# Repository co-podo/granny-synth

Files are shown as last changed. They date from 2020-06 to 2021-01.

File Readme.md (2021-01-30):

# Granny Synth

Adrian Ludwig
 Im Sack 11
 86152 Augsburg
 +49 157 71704314
hello@adrianludwig.de

Codrin Podoleanu
 Liebigstraße 61
 64293 Darmstadt
 +49 152 52022433
codrin.podoleanu@hs-augsburg.de

#### Abstract

GrannySynth ist ein Prototyp für ein Hard-/Softwaresystem für Granularsynthese in Echtzeit für Liveperformances und Sounddesign. Er enstand 2020 im Kurs "Interaktion/Programmierung" bei Prof. Dr. Thomas Rist an der Hochschule Augsburg. Eine Videodemonstration des Systems finden Sie [hier](https://vimeo.com/506451315).

 #### Klassifizierung und Einordnung

C.3 [SPECIAL-PURPOSE AND APPLICATION-BASED SYSTEMS] *,* H5.5 [SOUND AND MUSIC COMPUTING], [H.5.2](http://www.acm.org/about/class/ccs98-html#H.5.2) [USER INTERFACES]

#### General Terms

Design, Experimentation, Soundsynthesis

#### Keywords

Granularsynthese, Raspberry Pi, Pure Data, Liveperformance

#### 1. Motivation

##### Problemstellung: Granulare Synthese 

Wir interessieren uns für das Feld des Sounddesigns und suchen nach neuen Mitteln für Klanggestaltung. Eine sehr vielseitige Möglichkeit Klänge zu Formen ist die sogenannte "Granularsynthese". Vor allem in der Improvisation lassen sich mit dieser Syntheseart stark eigenständige, eindrucksvolle Klänge erzeugen.

Da es sich um eine digitale Syntheseart handelt, gibt es bereits ein Vielzahl an Software-Synthesizern. Diese eignen sich für die Liveperformance nur bedingt, benötigen sie doch immer einen Rechner mit einer entsprechenden DAW. Vor allem in der Außenwahrnehmung durch Publikum entsteht dabei häufig der Eindruck, dass weniger Live auf der Bühne geschieht, als dass vieles vom Rechner abgespielt wird. Diese Wahrnehmung ist verständlich, sieht es manchmal doch tatsächlich so aus, als würde man seine Mails checken, wenn man angestrengt auf einen Bildschirm sieht. 

Ziel von Granny Synth ist es, dieses Problem zu beseitigen, indem auf Basis eines Kleinstrechners und geeigneter Interfacegestaltung ein Liveperformance-geeigneter Granularsynthesesystem gestaltet wird.

Dieses Paper beschreibt die Erstellung eines Prototypen des Systems "Granny Synth". Folgende Schritte werden im folgenden durchlaufen:

- Motivation

- Verwandte Arbeiten

- Anwendungszenarion

  - Anwendungsfall allgemein
  - Konkreter Anwendungsfall

- Entwurf des Prototyps

  - Technischer Ansatz
  - Konzeptueller Aufbau des Prototypen

- Implementierung

  - Hard- und Softwareumgebung
  - Kern der Implementierung
  - Umfang des Prototypen

- Evaluation

  - Ziele der Evaluation und Methodik
  - Durchführung der Evaluation
  - Interpretation der Evaluationsergebnisse

- Zusammenfassung

  - Erzielte Ergebnisse
  - Erweiterungsmöglchkeiten

#### 2. Verwandte Arbeiten

Wie in der Motivation beschrieben, gibt es bereits eine Vielzahl von Softwarelösungen für Granulare Synthese. Ein Prominentes Beispiel ist der in Ableton Live (Digital Audio Workstation) verfügbare [Granulator]( https://www.monolake.de/technology/granulator.html)

Diese Implementierung der Granularsynthese besticht durch eine vielzahl von Parametern und eine Verhältnismäßig einfache Bedienbarkeit. Dazu trägt insbesondere das sinnvoll gestaltete Bedieninterface entscheidend bei. 

In der Welt der Hardware finden sich vergleichsweise wenig Implementierungen von brauchbarer Granularsynthese. Am häufigsten noch sind Lösungen im Bereich der Modularen Synthesizersysteme zu finden. Ein prominentes Beispiel hier ist [Mutable Instruments Clouds Eurorack-Modul](https://mutable-instruments.net/modules/clouds/ ). Hier besteht das Problem, dass man darauf angewiesen ist, ein entsprechendes Rack mit allen weiteren nötigen Modulen aufzubauen. Das ist aufwändig und vor allem teuer.

Ein System, das aufgrund seines Aufbaus viele Arten der Synthese zulässt, indem es auf die Open Source Software "Pure Data" zurückgreift, ist [Critter and Guitaris Organelle](https://www.critterandguitari.com/organelle). Dabei kommt es auf die Community an, die neue Patches auch frei zur Verfügung stellen kann. Dieses System funktioniert sehr gut, ist aber Aufgrund kleiner Auflagen eher teuer.

Aufgrund dieser vorhergehenden Arbeiten soll mit "Granny Synth" eine Lösung für entscheidende Probleme der genannten Beispiele geschaffen werden. 

Der Klangerzeugungsaufbau und die Modulationsparamter des Granulator dienen als Grundlage zur Gestaltung der Softwareseite.

Als Basis für das System soll - wie bei Critter and Guitaris "Organelle" ein Raspberry Pi und Pure Data dienen. Im Gegensatz zur Organelle setzen wir explizit auf granulare Synthese, sowie auf niedrigere Kosten.

#### 3.Anwendungsszenario & Use Case

##### 3.1 Portabler Granularsynthesizer

Entwicklung eines portablen, preiswerten Granularsynthesizers. Nutzer:innen sollen mit dem Gerät ein flexibles, portables Gerät für die Liveanwendung von Granularsynthese zur Hand haben. 

##### 3.2 Definition der Use Cases

Die wichtigsten Uses Cases werden im Folgenden erläutert.

###### 	3.2.1 Hardwaresystem für Granularsynthese

Ein:e Nutzer:in benutzt das System um einen Granularen Synthesizer zu steuern. Dafür werden die eingesetzten Hardwarekomponenten zur Kommunikation zwischen Akteur:in und Hardwaresystem genutzt. 
  - User dreht Encoder im Uhrzeigersinn: 
       Inkrement eines Parameterwertes

  - User dreht Encoder gegen Uhrzeigersinn: 
       Dekrement einesParameterwertes

  - User drückt Encoder nach unten: 
       Modus des jeweiligen Encoders wird ausgewählt

###### 3.2.2 Modulares Hardwaresystem zur Bedienung von Pure Data 

Ein:e Nutzer:in definiert ein eigenes Pure Data Patch, das über die vorhandene Hardware gesteuert werden kann. Hierfür muss die Nutzer:in eine entsprechende Konfigurationsdatei für die Hardware, sowie ein „Pure Data“- Patch anlegen.

#### 4. **Entwurf des Prototyps**

##### 4.1 Technischer Ansatz

Das Gerät basiert auf der Hardwareseite aus einem Raspberry-pi 3, Fünf Ky-040 Drehencodern, sowie einem 20x4 Zeichen LCD Display. Die Komponenten befinden sich in einem einfachen, aus Holz gefertigten Gehäuse.
Zur Verarbeitung der IO-Befehle verwenden wir python und die zum Raspberry korrespondierende python Library RPi.GPIO. 
Als System für die Granularsynthese verwendet das System die Open Source Software „Pure Data“. 
Die Kommunikation zwischen GPIO und Pure Data erfolgt über das OSC-Protokoll.

##### 4.2 **Konzeptueller Aufbau des Prototypen**

Das System besteht aus mehreren, miteinander kommunizierenden Untersystemen. 

###### 4.2.1 GPIO - Server

Die Verarbeitung der Sensordaten erfolgt über einen GPIO-Server, der die entsprechenden Inputs und Outputs überwacht. Er empfängt die Signale von Encodern und Display und handlet die Ausgabe von Daten an das Display.

###### 4.2.2 OSC-Client

Die Kommunikation der GPIO Signale zur Audioverarbeitungssoftware erfolgt über einen OSC-Client.

###### 4.2.3 OSC-Server

In der Umgebung des Klangerzeugers empfängt ein Server die über OSC Übertragenen Befehle zur Kontrolle des Klangerzeugers.

###### 4.2.4. Klangerzeuger/Granularer Synthesizer

Die Audioverarbeitung erfolgt über eine eigene Sofware, in diesem Fall „Pure Data“.
Innerhalb der Software wird ein „Patch“ für die Granularsynthese angefertigt. Die Steuerung erfolgt über OSC. Das Programm steuert auch die Audioausgabe auf dem Gerät.

#### 5. Implementierung

##### 5.1. Hard- und Softwareumgebung

###### Hardware

- 5 x KY-040 Drehimpulsgeber
- 1 x 20x4 LCD-Display
- 1 x IC2 Adapter
- 1 x kurzes Breadboard
- 1 x Breakout-Adapter Rasperry pi
- 1 x Raspberrry Pi 3 B

Auf dem Raspberry Pi läuft das Debian-basierte Linux-Betriebssystem Raspbian. Als Sprache für die IO-Kommunikation wird Python genutzt. Die Signalverarbeitung, sowie sämtliche genutzte Software laufen auf dem Raspberry Pi. Folgende Software wird verwendet:

###### Software

**Pure Data**

Die Granularsynthese wurde in *Pure Data* umgesetzt. Pure data ist eine visuelle Programmiersprache, die Musiker:innen, Künstler:innen und Forscher:innen die Möglichkeit gibt Software zu entwickeln, ohne Code zu schreiben. Stattdessen werden Patches (Programme in Pure Data) durch das platzieren und verbinden von Objekten ersellt.

Wir haben die Pure Data Distribution *pd-L2ork* alias *Purr-data* verwedent, die ein verbessertes GUI und eine Vielzahl von nützlichen Bibliotheken enthält.

**Python**

Die Kommunikation zwischen den verscheidenen Komponenten geschiet über ein Python Programm, das wir geschrieben haben. Python ist eine Allzweck-Programmiersprache, die über eine Vielzahl von internen sowie externen Bibliotheken verfügt.

Folgende Bibliotheken haben wir benutzt:

- [RPi.GPIO](https://pypi.org/project/RPi.GPIO/)
- [ADAFRUIT_LCD1602](https://github.com/amusarra/raspberry-pi-access-via-ts-cns/blob/master/modules/Adafruit_LCD1602.py)
- [PCF857](https://github.com/amusarra/raspberry-pi-access-via-ts-cns/blob/master/modules/PCF8574.py)
- [KY040](https://github.com/martinohanlon/KY040/blob/master/ky040/KY040.py)
- [python-osc](https://pypi.org/project/python-osc/)
- sowie *math*, *threading*, *argparse* und *os* aus der Standardbibliothek

##### 5.2  Kern der Implementierung

Ein großer Teil der Arbeit war die Anfertigung des Pure Data Patches für die Granularsynthese, sowie die Kommunikation zwischen GPIO des Raspberry Pi und Pure Data.

Dabei war eine besondere Herausforderung das Einrichten des Betriebssystems und der Selbst erstellten Software, sowie die Modularisierung der Eingabe. Das System sollte so flexibel wie möglich bedienbar sein. Die Dreh/Switch-Encoder sollen so viele Parameter wie möglich zugänglich machen.

Softwareseitig ist der funktionelle Kern von GrannySynth die Implementierung der Granularsynthese als Pure Data Patch.

Der Subpatch *grain* beinhaltet die Referenz zum geladenen Audiosample sowie die Funktionalität das Sample zu lesen. Welcher Teil des Samples und wie schnell es gelesen wird, hängt von Variablen ab, die der Subpatch als Eingangsparameter bekommt.

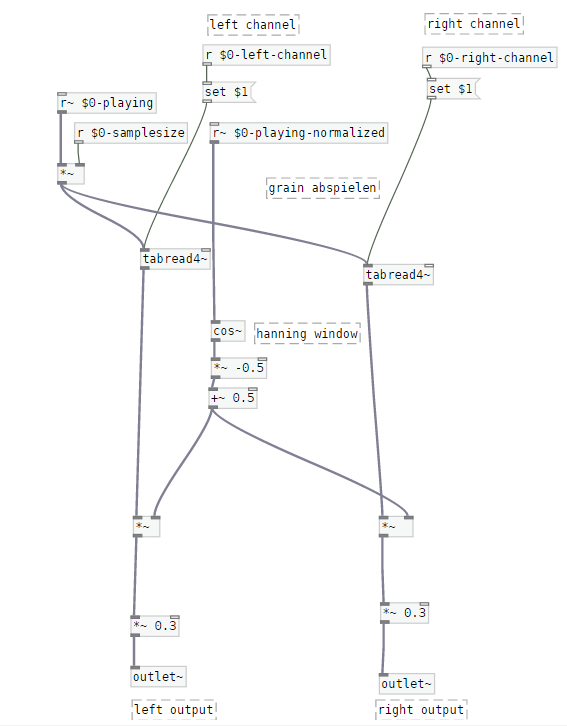
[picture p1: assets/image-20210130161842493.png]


Im Haupt-Patch *granny-synth* wird das Audiosample geladen, Parameter initialisiert sowie die OSC-Nachrichten, die die Parameterveränderungen beinhalten, empfangen und gespeichert. Der Patch liest das Sample kontinuierlich durch. Die gescannte Position des Samples, sowie die Parameter Länge und Tonhöhe, werden an die *grain* Objekte weitergeben, wenn ein Triggersignal gegeben wird. Dies hängt vom Parameter *Dichte* ab, der bestimmt wie oft ein neues Grain gestartet wird (es handelt sich hier einfach um die Frequenz eines Oszillators, der bei jeder Phase das Triggersignal gibt). Schließlich wird der Signalausgabe aller Grains gemischt und am Endgerät ausgegeben.

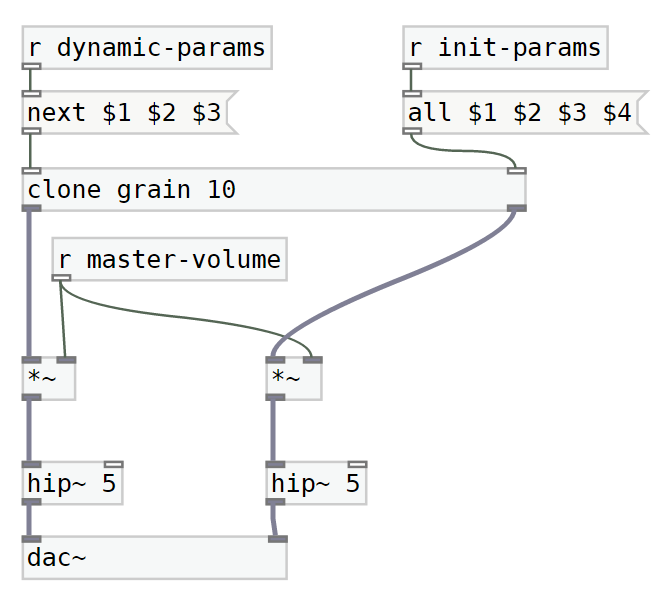
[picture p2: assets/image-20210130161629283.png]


##### 5.3 Umfang des Prototypen

Der Umfang des Prototypen beschränkt sich auf ein Proof of Concept. Dabei funktioniert das Laden eines Samples für die Granularsynthese, sowie die Steuerung der wichtigsten Parameter über die Hardware.

DSCF9162

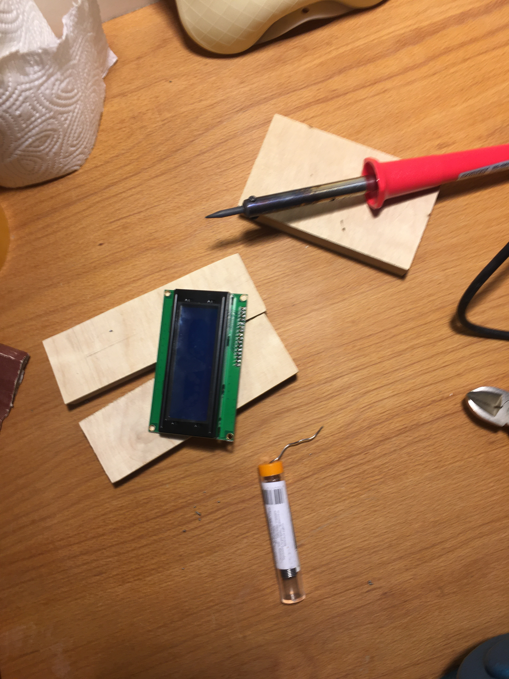
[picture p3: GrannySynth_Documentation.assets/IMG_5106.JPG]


DSCF9163

DSCF9165

**5.3.1 Implementiert**

Die grundsätzliche Funktionalität ist vorhanden. Die Drehregler können bedient werden, um damit Parameter in Pure Data Patch zu verändern. Durch einen fünften Drehregler kann zwischen mehreren Modi gewechselt werden. Es wurden zwei Modi (Parameter der Granularsynthese und Settings) implementiert. Das Display liefert visuelles Feedback in Echtzeit.

**5.3.2 Nicht Implementiert**

Das wohl größte fehlende Feature ist die Ansteuerung des Synthesizers durch MIDI ähnlich wie im *Granulator II* von Monolake.

Eine Effekt-Kette mit Filter, Delay und Reverb fehlt auch.

Außerdem fehlen LFOs als Modulationsquellen für die Parameter der Granularsynthese.

#### 6. Evaluation

##### 6.1 Ziele der Evaluation und Methodik

Ziel der Evaluation ist feszustellen, ob die Bedienung - ein vorhandenes Grundverständnis der Granularsynthese vorrausgesetzt - intuitiv und leicht erlernbar gestaltet ist. Darüber hinaus wird die technische Leistungsfähigkeit des GrannySynth soll evaluiert werden.

Das Gesamtziel der Evaluation ist vornehmlich festzustellen, ob das System als eigenständiges Hardwaresystem für Granularsynthese funktioniert.

Die Leistungsfähigkeit kann durch einen einfachen Lasttest erfolgen. Dazu werden die implementierten Parameter bezüglich der Systemperformance auf ihre Grenzbereiche eingestellt. Treten audio Artefakte wie hörbare Klicks auf, ist GrannySynth überlastet.

Dazu werden eine Vielzahl von Permutationen der Werte von Grainlänge, Graingröße, Graindichte sowie Grainanzahl getestet.

Anschließend werden Usertests durchgeführt, um bisher unentdeckte Fehler und Probleme festzustellen. Die User bekommen keine Anweisungen zur Nutzung des Systems und füllen nach einer Testzeit von 30 Minuten einen Fragebogen aus. Die Fragen werden mit einer Bewertung auf einer Skala von 1-10 beantwortet. Folgende Fragen sehen wir vor:

- Wie bewerten Sie das visuelle Feedback des GrannySynth?
- Wie bewerten Sie die Bedienung des GrannySynth?
- Wie bewerten Sie die Klangqualität des GrannySynth?
- Wie bewerten Sie die Gehäusequalität des GrannySynth? 
- Wie viel Spaß hatten Sie beim Test des GrannySynth?
- Wie inspiriert fühlen Sie sich nach der Nutzung des GrannySynth?
- Inwieweit konnten Sie gezielt Klänge nach Ihrer Vorstellung gestalten?

Zusätzlich können User in einem "Sonstiges"-Feld frei schriftliche Angaben zu Punkten machen, die Ihnen auffallen.

##### 6.2. Durchführung der Evaluation

Beim Lasttest des GrannySynth ist festzustellen, dass eine Grainanzahl über 10 zu Artefakten führt. Unterhalb dieser Grenze funktioniert das System wie gewünscht.

Die Evaluation über Usertests des Systems mit mehreren Usern war in der aktuellen Situation bisher nicht möglich. Die Usertests beschränken sich somit auf die Erfahrungen der Entwickler. 

##### 6.3. Interpretation der Evaluationsergebnisse

Die doch sehr beschränkte Grainanzahl ist wohl auf bestimmte Rechnungen im *grain* Subpatch zurückzuführen, die die Leistung bei einer höheren Anzahl von Grains strapaziert.

Es sollten alle unnötigen Rechnungen entfernt oder ausgelagert werden.

#### 7.Zusammenfassung

##### 7.1. Erzielte Ergebnisse

Wir haben ein Konzept für GrannySynth in Hinblick auf ein flexibles Hybrid-Synthesizer System entwickelt, dass sich durch analoge Bedienung und digitaler Klangerzeugung auszeichnet.

Wir erstellten einen Pure Data Patch, der Granularsynthese implementiert und OSC-Signale empfängt. Ein Python Programm, dass wir geschrieben haben, verarbeitet den Input und ist für die Kommunikation zwischen den Komponenten verantwortlich.

Wir haben die Hardware in ein Gehäuse verbaut, dass hinsichtlich des Status als Prototyp noch Veränderungen zulässt. Auf unserem Raspberry Pi wurden die Systemkonfigurationen passend eingestellt.

##### 7.2. Erweiterungsmöglichkeiten / Ausblick 

Wir erstellten einen Pure Data Patch, der Granularsynthese implementiert und OSC-Signale empfängt. Ein Python Programm, dass wir geschrieben haben, verarbeitet den Input und ist für die Kommunikation zwischen den Komponenten verantwortlich.

Wir haben die Hardware in ein Gehäuse verbaut, dass hinsichtlich des Status als Prototyp noch Veränderungen zulässt. Auf unserem Raspberry Pi wurden die Systemkonfigurationen passend eingestellt.

##### 7.2. Erweiterungsmöglichkeiten / Ausblick

Aus den fehlenden Implementierungen aus **5.3** sind die zusätzlichen Parameter der Effektkette wohl am einfachsten zu implementieren. Außerdem sollte ein config file erstellt werden, dass die Anpassung und Veränderung in Zukunft vereinfachen soll.

#### **Referenzen**

1. Implementing Real-Time Granular SynthesisRoss BencinaDraft of 31st August 2001 http://www.rossbencina.com/static/code/granular-synthesis/BencinaAudioAnecdotes310801.pdf
2. Granular Synthesis - How It Works & Ways To Use It - Simon Price, December 2005 https://www.soundonsound.com/techniques/granular-synthesis
3. Granulator II - Robert Henke - https://roberthenke.com/technology/granulator.html
4. Granularsynthese mit Pure Data - http://www.pd-tutorial.com/german/ch03s07.html
5. Pythonosc - https://pypi.org/project/python-osc
6. Python GPIO https://www.raspberrypi.org/documentation/usage/gpio/python/README.md
7. Raspberry Pi and realtime, low-latency audio - https://wiki.linuxaudio.org/wiki/raspberrypi
8. Granular Synthesis - http://www.sfu.ca/~truax/gran.html

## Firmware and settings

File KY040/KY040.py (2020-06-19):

"""
KY040 Python Class
Martin O'Hanlon
stuffaboutcode.com


Additional code added by Conrad Storz 2015 and 2016
"""

import RPi.GPIO as GPIO
from time import sleep


class KY040:

    CLOCKWISE = 0
    ANTICLOCKWISE = 1
    DEBOUNCE = 12

    def __init__(self, clockPin, dataPin, switchPin, rotaryCallback, switchCallback):
        #persist values
        self.clockPin = clockPin
        self.dataPin = dataPin
        self.switchPin = switchPin
        self.rotaryCallback = rotaryCallback
        self.switchCallback = switchCallback

        #setup pins
        GPIO.setup(clockPin, GPIO.IN, pull_up_down=GPIO.PUD_UP)
        GPIO.setup(dataPin, GPIO.IN, pull_up_down=GPIO.PUD_UP)
        GPIO.setup(switchPin, GPIO.IN, pull_up_down=GPIO.PUD_UP)

    def start(self):
        GPIO.add_event_detect(self.clockPin, GPIO.FALLING, callback=self._clockCallback, bouncetime=self.DEBOUNCE)
        GPIO.add_event_detect(self.switchPin, GPIO.FALLING, callback=self.switchCallback, bouncetime=self.DEBOUNCE)

    def stop(self):
        GPIO.remove_event_detect(self.clockPin)
        GPIO.remove_event_detect(self.switchPin)
    
    def _clockCallback(self, pin):
        if GPIO.input(self.clockPin) == 0:
            self.rotaryCallback(GPIO.input(self.dataPin))
        """
            data = GPIO.input(self.dataPin)
            if data == 1:
                self.rotaryCallback(self.ANTICLOCKWISE)
            else:
                self.rotaryCallback(self.CLOCKWISE)
        
        self.rotaryCallback(GPIO.input(self.dataPin))
        """

    def _switchCallback(self, pin):
        """
        if GPIO.input(self.switchPin) == 0:
            self.switchCallback()
        """
        self.switchCallback()

#test
if __name__ == "__main__":

    print ('Program start.')

    CLOCKPIN = 27
    DATAPIN = 22
    SWITCHPIN = 17

    def rotaryChange(direction):
        print ("turned - " + str(direction))
    def switchPressed(pin):
        print ("button connected to pin:{} pressed".format(pin))

    GPIO.setmode(GPIO.BCM)
    ky040 = KY040(CLOCKPIN, DATAPIN, SWITCHPIN, rotaryChange, switchPressed)

    print ('Launch switch monitor class.')

    ky040.start()
    print ('Start program loop...')
    try:
        while True:
            sleep(10)
            print ('Ten seconds...')
    finally:
        print ('Stopping GPIO monitoring...')
        ky040.stop()
        GPIO.cleanup()
        print ('Program ended.')

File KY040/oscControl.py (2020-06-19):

import RPi.GPIO as GPIO
from KY040 import KY040
import os, time
from pythonosc import udp_client
import argparse

# Init OSC

parser = argparse.ArgumentParser()
parser.add_argument("--ip", default="127.0.0.1",
    help="The ip of the OSC server")
parser.add_argument("--port", type=int, default=5005,
    help="The port the OSC server is listening on")
args = parser.parse_args()

client = udp_client.SimpleUDPClient(args.ip, args.port)

# for x in range(10):
#     client.send_message("/filter", random.random())
#     time.sleep(1)

def readVolume():
    value = os.popen("amixer get PCM|grep -o [0-9]*%|sed 's/%//'").read()
    return int(value)
def rotaryChange(direction):
    try:    
	    client.send_message("/rotation", direction)
    except:
	    print ("not connected")

def switchPressed(SWITCHPIN):
     print ("button pressed")


 
if __name__ == "__main__":
 
    CLOCKPIN = 4                                        
    DATAPIN = 17
    SWITCHPIN = 27 
    
    CLOCKPIN1 = 22
    DATAPIN1 = 5
    SWITCHPIN1 = 6
    
    CLOCKPIN2 = 13 
    DATAPIN2 = 19
    SWITCHPIN2 = 26
    
    CLOCKPIN3 = 16
    DATAPIN3 = 20
    SWITCHPIN3 = 21
     
    CLOCKPIN4 = 23
    DATAPIN4 = 24
    SWITCHPIN4 = 25
    
   
   
    
    GPIO.setmode(GPIO.BCM)
    
    button0 = KY040(CLOCKPIN, DATAPIN, SWITCHPIN, rotaryChange, switchPressed)
    button1 = KY040(CLOCKPIN1, DATAPIN1, SWITCHPIN1, rotaryChange, switchPressed)
    button2 = KY040(CLOCKPIN2, DATAPIN2, SWITCHPIN2, rotaryChange, switchPressed)
    button3 = KY040(CLOCKPIN3, DATAPIN3, SWITCHPIN3, rotaryChange, switchPressed)
    button4 = KY040(CLOCKPIN4, DATAPIN4, SWITCHPIN4, rotaryChange, switchPressed)
 
    button0.start()
    button1.start()
    button2.start()
    button3.start()
    button4.start()
 
    try:
        while True:
            time.sleep(0.05)
    finally:
        button0.stop()
    button1.stop()
    button2.stop()
    button3.stop()
    button4.stop()
    GPIO.cleanup()

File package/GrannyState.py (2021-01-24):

from package.views.GrannyStateView import GrannyStateView
class GrannyState:
    def __init__(self, name = None, knobs = [None, None, None, None], viewManager = None):
        self.name = name
        self.knobs = knobs

        viewParamNames = []
        viewParamValues = []
        for knob in knobs:
            viewParamNames.append(knob.paramName)
            viewParamValues.append(knob.value)

        self.view = GrannyStateView(viewManager, name, viewParamNames, viewParamValues)

    def rotateKnob(self, knobIndex, direction):
        knob = self.knobs[knobIndex]
        value = knob.rotate(direction)
        self.view.displayParam(knobIndex, value)
#         self.view.display()

    def pressKnob(self, knobIndex):
        knob = self.knobs[knobIndex]
        knob.press()

    @property
    def parameters(self):
        params = []
        for knob in self.knobs:
            params.append(knob.parameter)
        return params

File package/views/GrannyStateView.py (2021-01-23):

class GrannyStateView:
    def __init__(self, viewManager, name = "name", paramNames = ["par1", "par2", "par3", "par4"], paramValues = ["val1", "val", 0, 0]):
        self.lineSize = 20
        self.lines = 4
        self.paramSizes = [5, 4, 4, 4]
        self.namePosition = int((self.lineSize / 2) - 3)
        self.lineNames = ["stateName", "paramNames", "paramValues", "empty"]
        self.borderThickness = 1
        self.displayText = ["--------------------", "-----|----|----|----", "-----|----|----|----", "--------------------"]
        self.empty = " "

        self.viewManager = viewManager

        self.initDisplay(name, paramNames, paramValues)

    def changeParam(self, index, value, line = 2):
        y = line
        x = 0
        for paramIndex in range(index):
            x += self.paramSizes[paramIndex] + self.borderThickness

        size = self.paramSizes[index]
        value = str(value)[:size]
        value = value.rjust(size, self.empty)

        self.displayText[y] = self.displayText[y][0:x] + value + self.displayText[y][x+size:]

        return {"x": x, "y": y, "value": value}

    def displayParam(self, index, value, line = 2):
        returnVal = self.changeParam(index, value, line)
        x = returnVal["x"]
        y = returnVal["y"]
        value = returnVal["value"]
        self.viewManager.changeDisplay(x, y, value)


    def display(self):
        fullText = ""
        for i in range(len(self.displayText)):
            line = self.displayText[i]
            self.viewManager.changeDisplay(0, i, line)
            fullText += line + "\n" # DELETE LINEBREAK LATER
        # GPIO

        #self.viewManager.changeDisplay(0, 0, fullText)
        print(fullText)

    def initDisplay(self, name = "name", paramNames = ["par1", "par2", "par3", "par4"], paramValues = ["val1", "val", 0, 0]):          

        # name
        nameLine = self.emptyLine()
        nameLine = (nameLine[:self.namePosition] + name).ljust(self.lineSize, self.empty)
        self.displayText[self.lineNames.index("stateName")] = nameLine

        # paramNames
        for index in range(len(paramNames)):
            lineNumber = self.lineNames.index("paramNames")
            paramName = paramNames[index].ljust(self.paramSizes[index], self.empty)
            self.changeParam(index, paramName, lineNumber)

        # paramValues
        for index in range(len(paramValues)):
            lineNumber = self.lineNames.index("paramValues")
            paramValue = paramValues[index]
            self.changeParam(index, paramValue, lineNumber)
            
        # empty line
        self.displayText[self.lineNames.index("empty")] = self.emptyLine()
        self.display()


    def emptyLine(self):
        return "".ljust(self.lineSize, self.empty)

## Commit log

2020-05-21 - now properly scans through sample even at very low grain size
2020-05-28 - playbackspeed adjustable (independently from pitch) - basic monophonic midi control (no amplitude envelope yet)
2020-06-19 added files for buttons
    [RaspberryPiKY040.fzz]
2020-06-19 added button recognition to osc Data
2020-06-25 created working communication between PD and python
    [RaspberryPiKY040.fzz]
2021-01-05 changed button layout to pcb layout
2021-01-13 Merged Display and Button python Stuff into GPIO
2021-01-16 added singlefile GPIO Handler for Buttons and Display
2021-01-20 added proper format paper, removed unnecessary stuff in raspberryGPIO
2021-01-21 - changed increment functionality - added rudimentary LoadKnob for sample loading
2021-01-23 added sample
2021-01-23 button loop unclear
2021-01-23 - added threading for button loop
2021-01-24 reinstated stop functions for buttons 1-4 in grannyviewmanager
2021-01-24 - readded clamp
2021-01-24 - added incr control - added sample selection
2021-01-30 removed unnecessary files and folders
    [RaspberryPiKY040.fzz]
2021-01-30 added fritzzing file
    [granny_synth.fzz]
